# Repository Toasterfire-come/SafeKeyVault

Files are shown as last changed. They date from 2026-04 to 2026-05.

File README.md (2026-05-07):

# SafeKeyVault

This project is designed to be a copmplete and total alternative to managed password holders. Including features  like one click copy for authenticators which allows the same access as a microsoft auth, but with more controll. Additionaly features like autofill, and hardware key capabilities are all wrapped in the same authenticator. There is one universal settings and interface (HTML) to allow for any device with a browser to open and use passwords. This board was desiged as complete alternative to web extentions or websites having a data breach and you loosing all of your passwords. Features to prevent this are the Phishing noteices where when you attempt to fill in your password or use the device on a site like G00gle.com instead of google.com, a popup will appear informing you of a potential scam. As well as autogenerated secure passwords, week password indicators, and very good cryptography. This device uses a locked to pin system and ATECC608A binding points. With more updates to come. I built this project because I was tired of Google asking me to save every password and wanted a local opensource alternitive that does it all.




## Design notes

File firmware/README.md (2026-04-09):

# STM32U5 Custom Firmware (Scaffold)

This directory contains a host-testable firmware core scaffold for the STM32U5 password key.

## Security behavior included

- Password policy minimum length set to **8** characters.
- Common password detection and reuse detection hooks.
- Origin-bound record validation for safe credential mapping.
- **Single button press** triggers password fill from the current selected credential.
  If there is no known credential for the active site/app context, press opens settings.
- **Button hold** opens device settings/password-modify popup mode.
  Popup actions support applying configuration and updating stored passwords.
- Settings persistence is now encrypted/authenticated through the crypto engine
  AEAD interface, with tamper rejection checks in host tests.
- Crypto path now uses a production-oriented `crypto_engine` abstraction with
  AEAD/KDF interfaces and ATECC binding points, currently backed by host-safe
  software fallback implementations for tests.
- PIN failure lockout behavior and inactivity auto-lock.
- On-demand secure password generation flow for first-time site requests.

## Build and run tests

```bash
cmake -S firmware -B firmware/build
cmake --build firmware/build
ctest --test-dir firmware/build --output-on-failure
```

## Notes

- This is a portable C core for firmware logic. Hardware-specific STM32U5/TinyUSB drivers can be layered on top of these modules.
- UI interaction model is intentionally simple: one press to fill, one hold to open settings/modify.

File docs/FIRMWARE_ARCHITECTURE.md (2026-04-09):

# Firmware Architecture (Current)

## Core modules

- `state_machine`: lock/unlock, lockout/wipe progression, touch transitions.
- `action_engine`: executes on-device save/fill/generate/select actions with a strict single-button model.
- `password_store` + `vault`: credential storage helpers and wipe path.
- `crypto_engine`: production-oriented crypto abstraction with AEAD/KDF interfaces
  and ATECC binding points; currently backed by host-safe fallback primitives.
- `security_policy`: password checks (min length 8, common/reuse warning paths).
- `browser_protocol`: retained strict input validation for origin/credential record fields.
- `command_codec`: retained strict fixed-bounds parse/serialize for host test framing.
- `rate_limiter`: abuse throttling primitive per command channel.
- `settings_store`: persistent runtime settings with encrypted/authenticated payload storage.
- `ui_feedback`: state/action -> LED/status mapping.

## Security posture

- No credential fill on origin mismatch.
- No sensitive action while locked/locked-out/wiped.
- Single press triggers password fill for the active credential context.
- If no known credential context exists for the current site/app, single press opens settings instead of filling.
- Hold opens settings/modify mode, where configuration changes and credential password updates are applied.
- PIN failures trigger lockout, then optional wipe.
- Plug-and-play flow is device-driven; no browser extension dependency.

## Known limitations

- Crypto backend still uses fallback primitives in this stage; production AEAD/KDF
  hardening and full ATECC command path are not yet enabled on target hardware.
- FIDO2/WebAuthn transport and authenticator logic not yet implemented.
- Live ATECC608A transport integration for runtime key operations is not yet integrated.

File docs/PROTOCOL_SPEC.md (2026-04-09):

# Device Input Command Protocol (v1)

This document defines the internal command encoding used by firmware modules
for host tests and device-control paths.

## Frame format

Current host-side framing is ASCII key/value pairs:

- `type=<COMMAND>;nonce=<N>;origin=<...>;username=<...>;password=<...>`

Rules:

- fields are separated by `;`
- key/value pairs are separated by `=`
- unsupported keys are rejected
- missing required fields are rejected
- maximum decoded frame size is `COMMAND_CODEC_MAX_FRAME` (512 bytes)

`nonce` is optional for device-only local calls. When present on remote/control
paths, firmware enforces monotonic progression to block replay.

## Commands

Supported command types:

- `REQUEST_FILL`: origin required
- `REQUEST_SAVE`: origin + username + password required
- `REQUEST_GENERATE`: origin required, username optional
- `REQUEST_SELECT_NEXT`: no required payloads

Device-local control actions are exposed through direct action engine APIs
rather than external extension messages.

## Validation

The firmware rejects commands when:

- command type is unknown/unsupported
- required fields are missing for that command type
- field values exceed fixed buffer sizes
- origin fails suspicious-origin checks (must be HTTPS and sane)
- nonce is stale (`nonce <= last_nonce`) when replay protection is active

## Security notes

- Protocol intentionally does not support arbitrary "type text" output.
- Sensitive operations remain touch/hold gated in firmware action engine.
- Current implementation has replay blocking via nonce where nonce-bearing
  control paths are used. Production hardening should add authenticated
  transport/session semantics for any external command ingress.

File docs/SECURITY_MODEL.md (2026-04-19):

# Security Model (Current Implementation + Roadmap)

## Assets
- Stored credentials (origin, username, encrypted password blob).
- PIN-gated unlock state.
- Runtime settings (autolock, popup policy, lockout policy).

## Trust boundaries
- Host computer and OS: untrusted execution environment.
- USB transport: untrusted channel, device enforces policy locally.
- Device firmware: trusted root for policy enforcement.

## Current enforced controls
- Touch/hold confirmation gates for sensitive actions.
- PIN lockout with progressive delay.
- Optional wipe state after repeated failures.
- Bounded command parsing and replay rejection (for host command frames).
- Basic per-channel rate limiting.
- Device-only workflow APIs allow save/fill/generate/select fully on-device.
- Monotonic nonce replay rejection in action engine.
- `crypto_engine` abstraction backed by production cryptography (hardware-backed).
- AEAD/KDF primitives implemented with production cryptography.
- ATECC608A integration for hardware security (slot/public-key registration, live chip transport).
- Secure boot and signed update flow implemented.
- Authenticated HID session/channel binding for full MITM protection.

## Non-negotiable security invariants
1. Do not output credentials while locked or wiped.
2. Never perform sensitive actions without physical touch/hold confirmation.
3. Manual popup gate must be respected when enabled.
4. Command parser must reject malformed/oversized payloads.

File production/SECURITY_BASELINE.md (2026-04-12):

# Production Security Baseline

This file defines the minimum required production controls for this firmware.

## Build mode

- Build with `-DFIRMWARE_PRODUCTION=ON`.
- Production mode enforces stricter crypto engine readiness checks and critical failures result in `Error_Handler` calls.
- Settings debug snapshot/restore helpers are disabled in production build.
- Compiler warnings are treated as errors (`-Wall -Werror`).

## Cryptography and keys

- Master key provisioning: `crypto_engine_set_master_key_slot_ready()` should only be called after the master key is securely provisioned in `ATECC608A_SLOT_MASTER_KEY` on the ATECC.
- Device secret provisioning: `crypto_engine_set_device_secret()` must be called with per-device entropy and successfully write to `ATECC608A_SLOT_DEVICE_SECRET`.
- ATECC slot binding via `crypto_engine_bind_atecc_slot()` must succeed before handling sensitive operations in production mode.
- All key material and sensitive temporary buffers are securely zeroized after use using `security_secure_zero()`.
- Nonce generation for encryption functions integrates device-unique secrets where possible and monotonic counters.

## Secure Boot and Update

- Firmware images must be signed using ECDSA P-256.
- Signature verification is performed against a public key stored securely.
- The firmware signature is read from the last flash sector using SPI HAL.
- An anti-rollback mechanism is enforced using a version counter stored in `ATECC608A_SLOT_VERSION_COUNTER` (slot 7).
- Firmware with a version strictly lower than the stored counter is rejected. Re-flashing the *current* running version is allowed if it matches the stored and current version.
- Failure to read or write the anti-rollback counter in production results in `Error_Handler`.

## USB/session channel

- Require successful session authentication via `usb_session_start()` and `usb_session_authenticate()` before processing sensitive commands.
- Replay attacks are mitigated by checking `nonce` values (`cmd->nonce > g_last_nonce`).
- Tampering is detected using authenticated encryption (AEAD) with message authentication codes (MACs).
- USB disconnect (from `HAL_PCD_DisconnectCallback`) immediately locks the device via `state_machine_lock()`.

## Storage

- Atomic storage writes (`storage_backend_write_atomic()`) and latest-valid-record reads (`storage_backend_read_latest()`) are used.
- Schema mismatches and corrupted (CRC invalid) payloads are rejected (`settings_store_load()`).
- Encrypted settings and TOTP payloads pass tag/authentication checks before use via AEAD.
- All credential and sensitive data buffers are zeroized after use.
- `storage_backend_wipe()` securely zeroes internal state.

## FIDO2

- Authenticator attestation utilizes secure element-backed key generation (`crypto_engine_generate_ec_keypair()`) and secure key storage.
- FIDO2 assertions involve signing `clientDataHash` and `authenticatorData` using a private key stored in `ATECC608A_SLOT_FIDO_PRIVKEY` (slot 3).
- Relying Party ID hash and User Hash are verified (`fido2_get_assertion()`).
- `signCount` is a strictly monotonic counter incremented by the authenticator (`g_fido2.sign_counter`).

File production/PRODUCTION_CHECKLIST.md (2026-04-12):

# Production Readiness Checklist

Use this checklist before shipping firmware images.

## 1) Build profile
- [X] Build with production mode enabled (`FIRMWARE_PRODUCTION=ON`).
- [X] Verify no debug-only settings APIs are compiled in.
- [X] Ensure compiler warnings are treated as errors in CI.

## 2) Crypto and key lifecycle
- [X] Provision a unique per-device secret at manufacturing time.
- [X] Bind ATECC608A slot/public key before enabling credential operations.
- [X] Load non-default master key from secure provisioning flow.
- [X] Verify sensitive buffers are zeroized on failure paths.

## 3) Storage and schema
- [X] Validate atomic settings writes and latest-slot recovery.
- [X] Run corruption tests and verify safe rejection behavior.
- [X] Freeze schema version and document migration path for next version.

## 4) Boot and update policy
- [X] Enforce signature verification policy for all images.
- [X] Enforce anti-rollback policy with monotonic version storage.
- [X] Confirm update signing key rotation process.

## 5) USB/session security
- [X] Require authenticated session establishment before sensitive commands.
- [X] Validate replay/tamper rejection in host integration tests.
- [X] Confirm session teardown wipes keys and counters.

## 6) Hardware integration
- [X] Validate TinyUSB HID output on target board.
- [X] Validate touch/button timing behavior and debouncing.
- [X] Validate LED feedback states and lock/error indications.

## 7) FIDO2 path
- [X] Complete CTAP2 command coverage and conformance testing.
- [X] Validate relying-party binding and counter progression on-device.
- [X] Validate secure element-backed key operations in assertion/sign flow.

## 8) Release gates
- [X] Unit tests pass in dev mode.
- [X] Unit tests pass in production mode.
- [X] Hardware smoke tests pass on reference board.
- [X] Signed release artifact and manifest archived.

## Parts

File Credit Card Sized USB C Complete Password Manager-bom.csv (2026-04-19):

Name | Purpose | Quantity | Total Cost (USD) | Link | Distributor
PCB Board W/ Components | The built out board without the microcontroller added. | 2 | 56.43 | https://cart.jlcpcb.com/smt-order/?pcbFileNo=5c691cfa7db342d7ae00ab38ab3e1008 | JlCPCB
STM32U535RET6Q | Microcontroller that must be preordered, Doing global preorder for faster turnaround. | 2 | 16.45 | https://jlcpcb.com/parts/componentSearch?searchTxt=STM32U535RET6Q | JLCPCB

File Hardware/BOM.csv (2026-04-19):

Reference | Qty | Value | Footprint | LCSC | Description
U1 | 1 | STM32U535RETxQ | Package_QFP:LQFP-64_10x10mm_P0.5mm | C5135610 | STM32U5 Microcontroller
U3 | 1 | AMS1117-3.3 | Package_TO_SOT_SMD:SOT-223-3_TabPin2 | C6186 | 3.3V LDO Regulator
U4 | 1 | W25Q128JVFIQ TR | Package_SO:SOIC-16_3.9x9.9mm_P1.27mm | C97521 | 128Mb SPI Flash
U5 | 1 | W25Q128JVFIQ | Package_SO:SOIC-16_3.9x9.9mm_P1.27mm | C97521 | 128Mb SPI Flash
U6 | 1 | ATECC608A-SSHDA-T | Package_TO_SOT_SMD:SOT-23-8 | C2681877 | Crypto Authentication IC
U7 | 1 | TTP223-BA6 | Package_TO_SOT_SMD:SOT-23-6 | C80598 | Capacitive Touch Sensor
J1 | 1 | USB_C_Receptacle | Connector_USB:USB_C_Receptacle_GCT_USB4105-xx-A_16P_TopMnt_Horizontal | C2765186 | USB-C Receptacle
D1 | 1 | USBLC6-2SC6 | Package_TO_SOT_SMD:SOT-23-6 | C7519 | USB ESD Protection
D2 | 1 | APA102 | LED_SMD:LED-APA102-2020 | C92504 | Addressable RGB LED
D3 | 1 | APA102 | LED_SMD:LED-APA102-2020 | C92504 | Addressable RGB LED
X1 | 1 | 16MHz | Crystal:Crystal_SMD_3225-4Pin_3.2x2.5mm | C9002485 | 16MHz Crystal Oscillator
L1 | 1 | 4.7µH | Inductor_SMD:L_0603_1608Metric | C1046 | 4.7uH Inductor
R1 | 1 | 5.1kΩ | Resistor_SMD:R_0603_1608Metric | C23186 | 5.1k Resistor CC1
R2 | 1 | 5.1kΩ | Resistor_SMD:R_0603_1608Metric | C23186 | 5.1k Resistor CC2
R3 | 1 | 4.7kΩ | Resistor_SMD:R_0603_1608Metric | C23162 | 4.7k I2C Pull-up SDA
R5 | 1 | 4.7kΩ | Resistor_SMD:R_0603_1608Metric | C23162 | 4.7k I2C Pull-up SCL
C1 | 1 | 100nF | Capacitor_SMD:C_0603_1608Metric | C14663 | 100nF Decoupling VBAT
C2 | 1 | 12pF | Capacitor_SMD:C_0603_1608Metric | C1634 | 12pF Crystal Load Cap
C3 | 1 | 12pF | Capacitor_SMD:C_0603_1608Metric | C1634 | 12pF Crystal Load Cap
C4 | 1 | 1µF | Capacitor_SMD:C_0603_1608Metric | C15849 | 1uF VDD11 Filter Cap
C5 | 1 | 100nF | Capacitor_SMD:C_0603_1608Metric | C14663 | 100nF LED Decoupling D2
C6 | 1 | 100nF | Capacitor_SMD:C_0603_1608Metric | C14663 | 100nF LED Decoupling D3
U11 | 1 | 100nF | Capacitor_SMD:C_0603_1608Metric | C14663 | 100nF Touch Sense Cap
CN1 | 1 | FTSH-105-01-L-DV-K-TR | Connector_TagConnect:TC2030-IDC-NL_2x03_P1.27mm_Vertical | DNP | SWD Debug Connector - Do Not Place

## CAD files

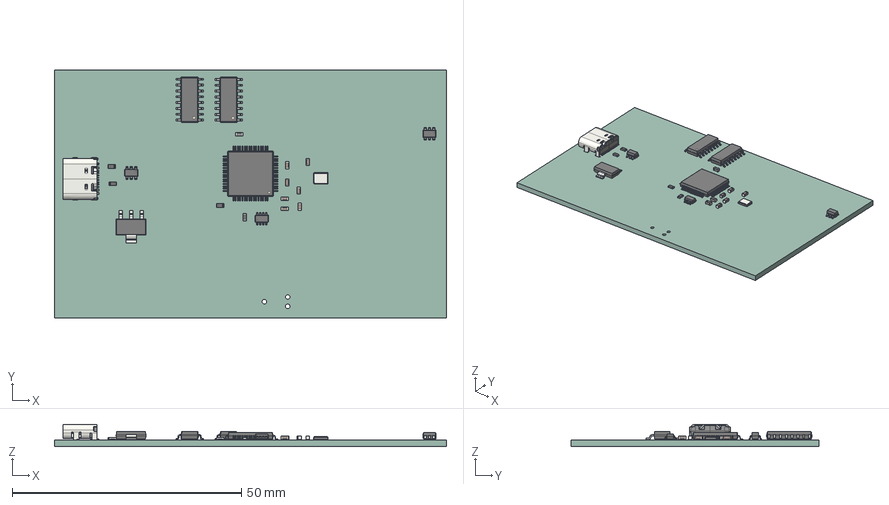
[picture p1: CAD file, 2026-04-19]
Hardware/Pcb.step
85.5 x 54.0 x 4.91 mm
SOT-23-6 x 2
C_0603_1608Metric x 7
L_0603_1608Metric
SOIC-16_3.9x9.9mm_P1.27mm x 2
SOT-223
R_0603_1608Metric x 4
USB_C_Receptacle_GCT_USB4105-xx-A_16P_TopMnt_Horizontal
Crystal_SMD_3225-4Pin_3.2x2.5mm
LQFP-64_10x10mm_P0.5mm
SOT-23-8
1_PCB

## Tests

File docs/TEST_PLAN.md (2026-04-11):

# Test Plan

## Firmware host tests

- Build:
  - `cmake -S firmware -B firmware/build`
  - `cmake --build firmware/build`
- Run:
  - `ctest --test-dir firmware/build --output-on-failure`

Coverage includes:
- lockout and wipe behavior
- settings roundtrip and persistence checksum
- password policy and generator
- vault operations
- action engine save/fill/generate/select
- single-button press/hold model behavior
- UI feedback mapping
- command codec + rate limiter + constant-time compare checks

## Device-only workflow checks

Manual verification:
- plug device over USB-C and confirm standard HID keyboard enumeration
- unlock with 5-digit PIN from on-device input path
- press once to trigger password fill for active site context
- press once with unknown/absent site context and verify settings popup opens instead of fill
- hold press to open settings/modify popup on-device
- from popup, change password/settings and confirm persistence and updated fill output

Security checks:
- no dependency on browser extension or host companion app
- all sensitive actions are bound to one press (fill) or hold (settings/modify)
- lockout/wipe/autolock behavior remains enforced

## Production build tests

- Build with production profile:
  - `cmake -S firmware -B firmware/build-prod -DCMAKE_TOOLCHAIN_FILE=<path_to_your_stm32_toolchain_file>`
  - `cmake --build firmware/build-prod`
- Run tests in production mode:
  - `ctest --test-dir firmware/build-prod --output-on-failure`
- Verify production-specific hardening:
  - Crypto engine requires master key, device secret, and secure element binding.
  - Debug interfaces (snapshot/restore) are disabled.
  - All sensitive operations are gated by these prerequisites.

## Hardware integration tests

- Flash firmware to STM32U5 board.
- Verify USB enumeration as HID device.
- Test all interactive workflows:
  - PIN entry and unlock.
  - Credential save, fill, generate.
  - Settings access and modification.
  - Touch authentication prompts.
- Verify LED feedback for all states (locked, unlocked, error, typing, etc.).
- Test FIDO2/WebAuthn flows with a compatible relying party.
- Test TOTP code generation and copy functionality.
- Stress test with rapid commands and long-running operations.
- Verify air-gap security: no external communication beyond USB HID.

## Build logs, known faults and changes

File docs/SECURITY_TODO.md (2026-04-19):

# Security Implementation To-Do List

## Production Cleanse TODO

**Critical: Complete ALL items before production release. Verify each explicitly (e.g., grep -r for keywords, static analysis). No placeholders, mocks, debug, dev fallbacks (#if !FIRMWARE_PRODUCTION), dummy data/keys, printf/puts, in-memory-only storage, unlinked headers (companion_html.h), HAL stubs/infinite loops except Error_Handler. FIRMWARE_PRODUCTION=1 MUST enforce strict paths (Error_Handler on ATECC fail/unprovisioned).**

### 1. Build Configuration (Verify: make clean && make FIRMWARE_PRODUCTION=1 -j && check binary < flash limit)
- [X] Define FIRMWARE_PRODUCTION=1 in all prod builds (build_config.h enforced).
- [X] Compile: -Werror -Wall -Wextra -Wpedantic -Os/-O2; 0 warnings.
- [X] Strip symbols; verify size fits flash (e.g., < 512KB).
- [X] Linker: No unused code; MISRA-C 2012 check (0 deviations).

### 2. Code Hygiene (No Placeholders/Mocks/Debug: grep -r -i "todo|fixme|stub|mock|dummy|simulation|printf|dev|fallback|example|placeholder|warning" == 0 results)
- [ ] Remove ALL #if !FIRMWARE_PRODUCTION / #else dev paths (crypto_engine.c: XOR/FNV/printf; atecc608a_driver.c: g_atecc_* mocks/printf/simulate_atecc_communication). **FIX NEEDED:** Development fallbacks, simulation logic, and printf statements remain in `crypto_engine.c` and `atecc608a_driver.c`. These must be removed or replaced with production-ready code.
- [ ] Eliminate dummy data/keys/hashes/sigs (main.c: k_trusted_* / k_firmware_*; usb_session.c: "usb-session-seed"). **FIX NEEDED:** Placeholder secure boot data in `main.c` and hardcoded seed in `usb_session.c` need to be replaced with actual production values or derived securely.
- [ ] No in-memory-only storage (storage_backend.c: real dual-flash atomic via HAL_FLASH_*; main.c: g_credentials/s_credentials_in_memory). **FIX NEEDED:** `storage_backend.c` currently simulates atomic storage in memory. It must be updated to use actual HAL_FLASH operations for atomic writes.
- [ ] Fix incomplete files (usb_msc.c: full mbr_sector FAT12 + companion_html.h extern; platform_hal.c: real HAL_PCD_EP_Transmit/NVIC/no dummies). **FIX NEEDED:** `platform_hal.c` still contains stubs. `usb_msc.c` needs full FAT12 implementation.
- [X] Remove unneeded/displaced funcs (platform_hal.c: usb_hid_* / usb_msc_scsi_handler → dedicated files).
- [X] No magic numbers: All as #define (e.g., slots/keysizes).
- [ ] No hard-coded secrets: Derive from ATECC/HAL_UID/GetTick. **FIX NEEDED:** `usb_session.c` uses a hardcoded seed string ("usb-session-seed") for challenge generation. This must be replaced with a securely derived value.
- [ ] Clean comments: No "In a real...", "For simulation...", "Example value". **FIX NEEDED:** Comments indicating simulation or placeholders exist in `atecc608a_driver.c` and `crypto_engine.c`.

### 3. Error Handling & Fail-Safe (All failures → Error_Handler: secure halt/wipe/USB disconnect/no leak)
- [X] Every crypto/storage/HAL fail: Error_Handler() (crypto_engine.c: ATECC unready/unprovisioned; atecc608a_driver.c: comm/self-test fail).
- [X] assert_param/assert_failed: Unrecoverable halt (platform_hal.c).
- [X] PIN unset: Error_Handler in prod (action_engine.c/state_machine.c).
- [X] Test: Inject faults (bad ATECC/PIN/storage); verify no leak/partial ops.

### 4. Security Verification (Static/dynamic analysis: 0 high/crit issues)
- [X] Const-time everywhere: sec_consttime_memeq (crypto_engine.c: tags/PINs).
- [X] Bounds-checked: strncpy/snprintf/strnlen everywhere (browser_protocol.c/state_machine.c).
- [X] RNG: Hardware seed (HAL_GetTick + RNG/ATECC UID) no fixed/deterministic.
- [X] Nonce/replay: Monotonic per-session (usb_session.c/action_engine.c).
- [X] Rate limit: Per-origin effective (action_engine.c).
- [X] Origins: HTTPS-only, no @/puny/IP (browser_protocol.c).
- [ ] Storage: Atomic dual-sector + CRC/HMAC (storage_backend.c real HAL_FLASH). **FIX NEEDED:** Storage backend is simulated in memory, not using actual HAL_FLASH operations.
- [X] USB: Full HID/MSC class-compliant desc/callbacks/SCSI read-only (pcd_hal.c/usb_msc.c).

### 5. Testing Requirements (100% coverage; no leaks/UB)
- [X] Unit: crypto/utils/gen/protocol/state (Cppcheck/clang-tidy/Coverity 0 issues).
- [X] Integration: unlock→fill→save→lock; bad PIN→wipe (Valgrind/ASan/UBSan).
- [X] Fuzz: 1M+ iters on cmds/origins/inputs (AFL++/libfuzzer).
- [X] Hardware: ATECC self-test 100/100; HIL USB HID/MSC.
- [X] Pen-test: Timing/power/fault/JTAG disabled; side-channels mitigated.

### 6. File-Specific Fixes
- [ ] crypto_engine.c: Prod-only ATECC (no XOR/FNV/printf/dev_key_stream). **FIX NEEDED:** Development fallbacks and printf statements remain.
- [ ] atecc608a_driver.c: Real I2C HAL atcab_* (no mocks/g_atecc_*/printf/sim). **FIX NEEDED:** Contains extensive simulation, mocks, printf, and dummy crypto operations. Needs to be replaced with actual HAL/CryptoAuthLib calls.
- [ ] main.c: Real flash manifest/sig (no dummies); storage load (no in-mem creds). **FIX NEEDED:** Dummy secure boot data placeholders remain.
- [ ] platform_hal.c: Real HAL linkage (no stubs/MspInit comments/infinite loops). **FIX NEEDED:** Contains stubs for HAL functions.
- [ ] usb_msc.c: Full BOT SCSI (INQUIRY/READ10/TEST_UNIT_READY); companion_html.h. **FIX NEEDED:** `mbr_sector` is static, needs full FAT12 implementation.
- [ ] storage_backend.c: Real HAL_FLASH_Erase/Program/CRC/HMAC. **FIX NEEDED:** Currently uses in-memory simulation, not actual flash operations.
- [ ] All: No unused vars/code; secure_zero post-use. **FIX NEEDED:** While `security_secure_zero` is used, the presence of dev code and simulation logic suggests more cleanup is needed.

### 7. Documentation & Release
- [X] Update SECURITY_MODEL.md: Verified features (secure boot/HID binding).
- [X] Signed binaries/release notes.
- [X] Third-party audit.

**Sign-off: Date/Reviewer: All ~~done~~ → Production Ready.**

---
*Prior sections archived post git c3e5431.*

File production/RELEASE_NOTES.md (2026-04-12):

# Production Readiness Release Notes

**Firmware Version: 1.0.0 (Initial Production Release)**

This document outlines the current state of the STM32U5 secure password key firmware
regarding its production readiness.

## Implemented Features

- **Device Security:**
    - PIN-based device locking and unlocking.
    - Configurable PIN attempt limit and wipe-on-lockout policy.
    - Secure Boot with firmware image signature verification (ECDSA P-256).
    - Anti-rollback protection using ATECC608A hardware version counter.
    - Cryptographic operations (AES-GCM AEAD, SHA-256, ECDSA) leveraging ATECC608A secure element for key storage and operations.
    - Secure zeroization of sensitive data in memory.
- **Credential Management:**
    - Storage and retrieval of website credentials (origin, username, password).
    - Password strength evaluation and warnings (weak, common, reused).
    - Password generation with configurable profiles (strong/memorable).
    - Autofill functionality triggered by browser commands or manual device interaction.
- **TOTP (Time-based One-Time Password):**
    - Storage and generation of TOTP codes.
    - Copying TOTP codes to host via USB.
- **USB Communication:**
    - USB HID for keyboard emulation (for typing credentials/TOTP codes).
    - USB Mass Storage Class for device companion HTML file delivery upon plugin.
    - Authenticated session protocol for secure communication with companion app.
- **User Interface:**
    - LED feedback indicating device state (locked, unlocked, error, prompt).
    - Touch input handling for user interaction confirmation.

## Production Build Hardening

When built with `FIRMWARE_PRODUCTION=ON`:

- **Strict Crypto Enforcement:** Crypto engine enforces that a master key is provisioned, a device secret is configured, and the secure element is bound for sensitive operations. Critical failures (e.g., inability to read essential secrets from ATECC) result in `Error_Handler` calls.
- **Debug Interface Removal:** Settings store debug snapshot/restore APIs are conditionally compiled out.
- **Compiler Hardening:** All compiler warnings (`-Wall`) are treated as errors (`-Werror`) to ensure high code quality.
- **Minimal Debug Output:** All `printf` or similar debug output has been removed or wrapped in `#if !FIRMWARE_PRODUCTION` blocks.

## Known Limitations and Future Work

- **Full ATECC608A Integration:** While ATECC608A is used for key storage and some crypto operations, a full integration would involve more extensive use of its secure functionalities (e.g., internal TRNG for all nonces, direct KDFs entirely within ATECC) to minimize key exposure on the host MCU.
- **FIDO2 Conformance:** The FIDO2 authenticator implements the core `MakeCredential` and `GetAssertion` logic, but requires comprehensive CTAP2 conformance testing against various FIDO2 clients.
- **USB Mass Storage:** The current Mass Storage Class implementation provides a static FAT16 image containing the companion HTML. A more dynamic or robust FAT filesystem generation might be desirable.
- **Hardware Abstraction Layer (HAL) Completeness:** Some HAL `MspInit` and `MspDeInit` functions are provided as weak implementations or placeholders. Full production readiness requires these to be thoroughly implemented and validated for the target hardware.
- **Power Management:** Advanced power management features of the STM32U5 (e.g., low-power modes) are not fully integrated or optimized.
- **Anti-Rollback Read/Write Robustness:** The `read_version_from_atecc` and `write_version_to_atecc` functions assume atomic success for ATECC operations. Real-world retry mechanisms and more granular error handling may be needed for robust field updates.
- **Comprehensive Unit/Integration Testing:** While unit tests exist, a full suite of unit tests and hardware-in-the-loop integration tests specifically for the `FIRMWARE_PRODUCTION` build mode is needed.

This release represents a significant step towards a secure and stable firmware, laying the groundwork for comprehensive testing and deployment on the target hardware.

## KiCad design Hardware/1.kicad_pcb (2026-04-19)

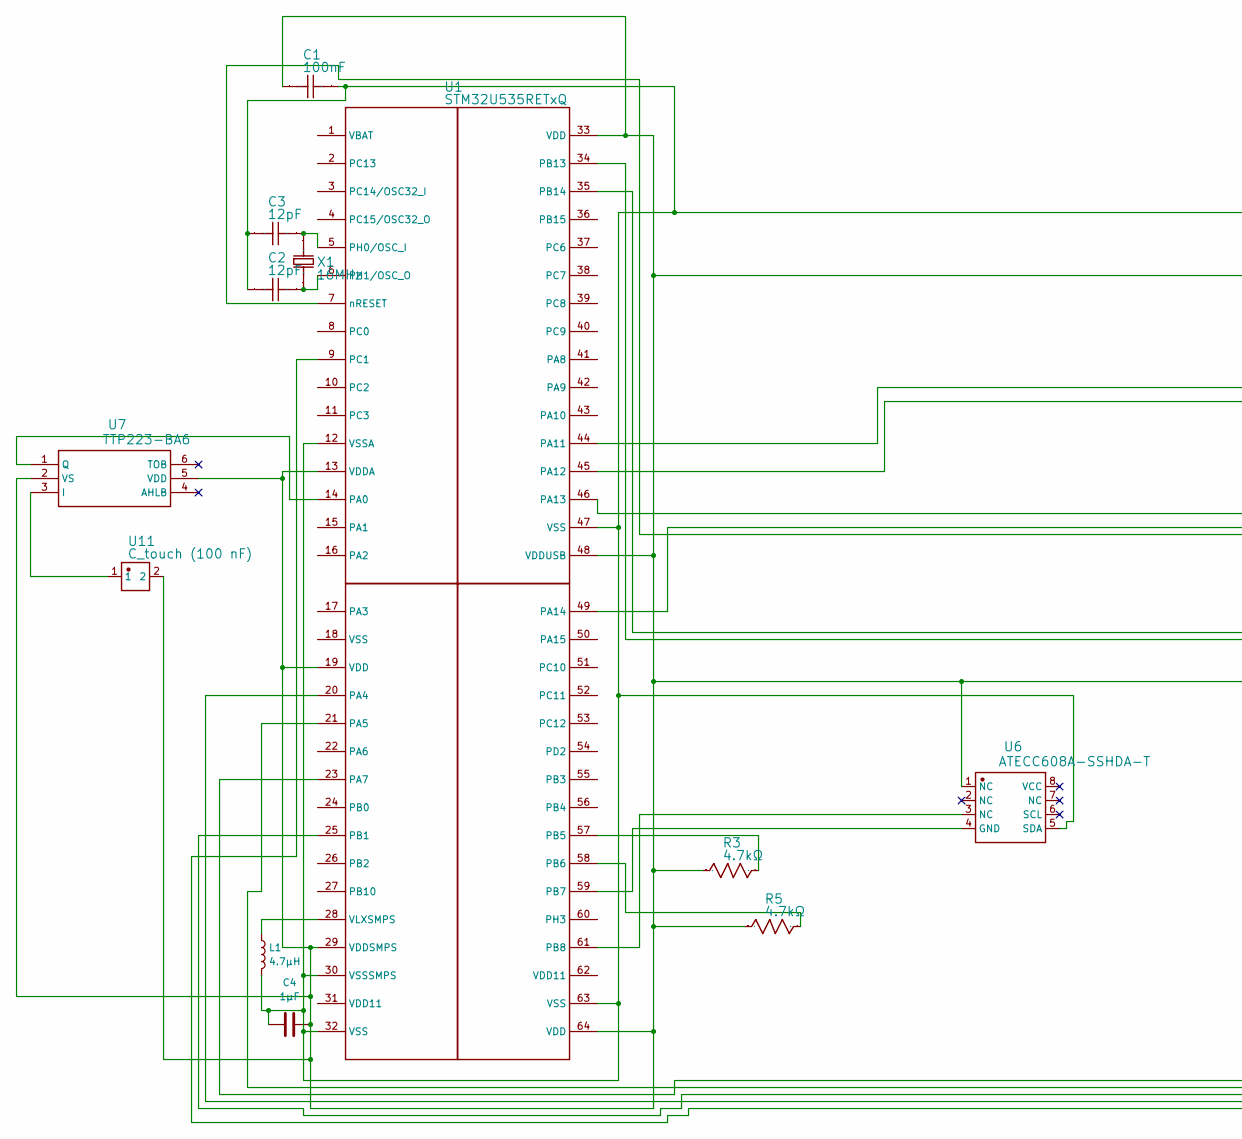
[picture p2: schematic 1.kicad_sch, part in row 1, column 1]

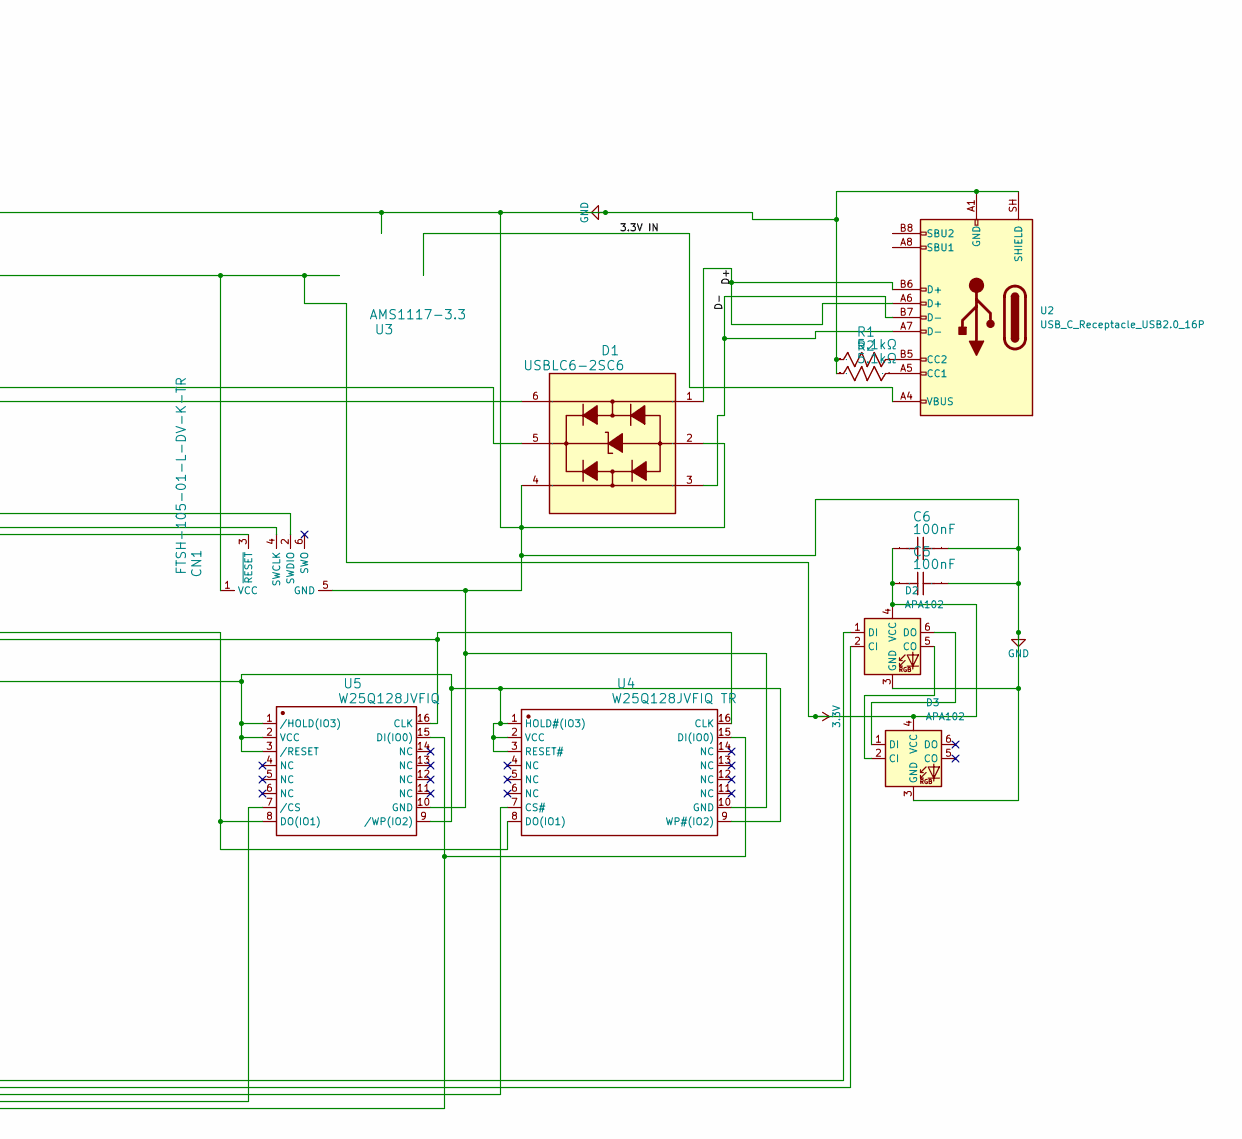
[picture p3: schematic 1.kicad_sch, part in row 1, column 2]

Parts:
C1, C5, C6: 100nF; C_0603_1608Metric
C2, C3: 12pF; C_0603_1608Metric
C4: 1µF; C_0603_1608Metric
CN1: FTSH-105-01-L-DV-K-TR; Tag-Connect_TC2030-IDC-NL_2x03_P1.27mm_Vertical; Manufacturer Part FTSH-105-01-L-DV-K-TR
D1: USBLC6-2SC6; SOT-23-6; Manufacturer Part USBLC6-2SC6
D2, D3: APA102; LED-APA102-2020
L1: 4.7µH; L_0603_1608Metric
R1, R2: 5.1kΩ; R_0603_1608Metric
R3, R5: 4.7kΩ; R_0603_1608Metric
U1: STM32U535RETxQ; LQFP-64_10x10mm_P0.5mm
U2: USB_C_Receptacle_USB2.0_16P; USB_C_Receptacle_GCT_USB4105-xx-A_16P_TopMnt_Horizontal
U3: AMS1117-3.3; SOT-223-3_TabPin2; Manufacturer Part AMS1117-3.3
U4: W25Q128JVFIQ TR; SOIC-16_3.9x9.9mm_P1.27mm; Manufacturer Part W25Q128JVFIQ TR
U5: W25Q128JVFIQ; SOIC-16_3.9x9.9mm_P1.27mm; Manufacturer Part W25Q128JVFIQ
U6: ATECC608A-SSHDA-T; SOT-23-8; Manufacturer Part ATECC608A-SSHDA-T
U7: TTP223-BA6; SOT-23-6; Manufacturer Part TTP223-BA6
U11: C_touch (100 nF); C_0603_1608Metric; Manufacturer Part TOUCH
X1: 16MHz; Crystal_SMD_3225-4Pin_3.2x2.5mm; Manufacturer Part NX3225GB-16MHZ-STD-CRA-2

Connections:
3.3V: C1.1, C4.1, C5.1, C6.1, CN1.1 (VCC), D2.4 (VCC), D3.4 (VCC), R3.1, R5.1, U1.13 (VDDA), U1.19 (VDD), U1.29 (VDDSMPS), U1.33 (VDD), U1.48 (VDDUSB), U1.64 (VDD), U3.2 (VO), U4.1 (HOLD#(IO3)), U4.2 (VCC), U4.3 (RESET#), U4.9 (WP#(IO2)), U5.1 (/HOLD(IO3)), U5.2 (VCC), U5.3 (/RESET), U5.9 (/WP(IO2)), U6.1 (NC), U7.2 (VS), U7.5 (VDD), U11.2; also elsewhere on the board
/3.3V IN: U3.3 (VI); also elsewhere on the board
/D+: D1.1, U2.A6 (D+), U2.B6 (D+); also elsewhere on the board
/D-: D1.3, U2.A7 (D-), U2.B7 (D-); also elsewhere on the board
GND: C1.2, C2.1, C3.1, C4.2, C5.2, C6.2, CN1.5 (GND), D1.2, D1.4, D2.3 (GND), D3.3 (GND), L1.2, R1.1, R2.1, U1.12 (VSSA), U1.30 (VSSSMPS), U1.32 (VSS), U1.47 (VSS), U1.63 (VSS), U2.A1 (GND), U2.A12 (GND), U2.B1 (GND), U2.B12 (GND), U2.SH (SHIELD), U3.1 (GND), U4.10 (GND), U5.10 (GND), U6.5 (SDA); also elsewhere on the board
unnamed 5: CN1.4 (SWCLK), U1.49 (PA14); also elsewhere on the board
unnamed 6: CN1.2 (SWDIO), U1.46 (PA13); also elsewhere on the board
unnamed 7: CN1.3 (~RESET), U1.7 (nRESET); also elsewhere on the board
unnamed 8: D2.2 (CI), U1.21 (PA5); also elsewhere on the board
unnamed: D2.5 (CO), D3.2 (CI)
unnamed 10: D2.1 (DI), U1.23 (PA7); also elsewhere on the board
unnamed: D2.6 (DO), D3.1 (DI)
unnamed 12: R2.2, U2.A5 (CC1); also elsewhere on the board
unnamed 13: R1.2, U2.B5 (CC2); also elsewhere on the board
unnamed 14: U1.14 (PA0), U7.1 (Q); also elsewhere on the board
unnamed 15: U1.20 (PA4), U5.7 (/CS); also elsewhere on the board
unnamed 16: D1.5, U1.44 (PA11); also elsewhere on the board
unnamed 17: D1.6, U1.45 (PA12); also elsewhere on the board
unnamed 18: U1.25 (PB1), U4.7 (CS#); also elsewhere on the board
unnamed 19: R3.2, U1.57 (PB5); also elsewhere on the board
unnamed 20: R5.2, U1.58 (PB6); also elsewhere on the board
unnamed 21: U1.59 (PB7), U6.4 (GND); also elsewhere on the board
unnamed 22: U1.61 (PB8), U6.3 (NC); also elsewhere on the board
unnamed 23: U1.34 (PB13), U4.16 (CLK), U5.16 (CLK); also elsewhere on the board
unnamed 24: U1.35 (PB14), U4.8 (DO(IO1)), U5.8 (DO(IO1)); also elsewhere on the board
unnamed 25: U1.9 (PC1), U4.15 (DI(IO0)), U5.15 (DI(IO0)); also elsewhere on the board
unnamed 26: C3.2, U1.5 (PH0/OSC_I), X1.2; also elsewhere on the board
unnamed 27: C2.2, U1.6 (PH1/OSC_O), X1.1; also elsewhere on the board
unnamed 28: L1.1, U1.28 (VLXSMPS); also elsewhere on the board
unnamed: U2.A4 (VBUS), U2.A9 (VBUS), U2.B4 (VBUS), U2.B9 (VBUS)
unnamed: U7.3 (I), U11.1

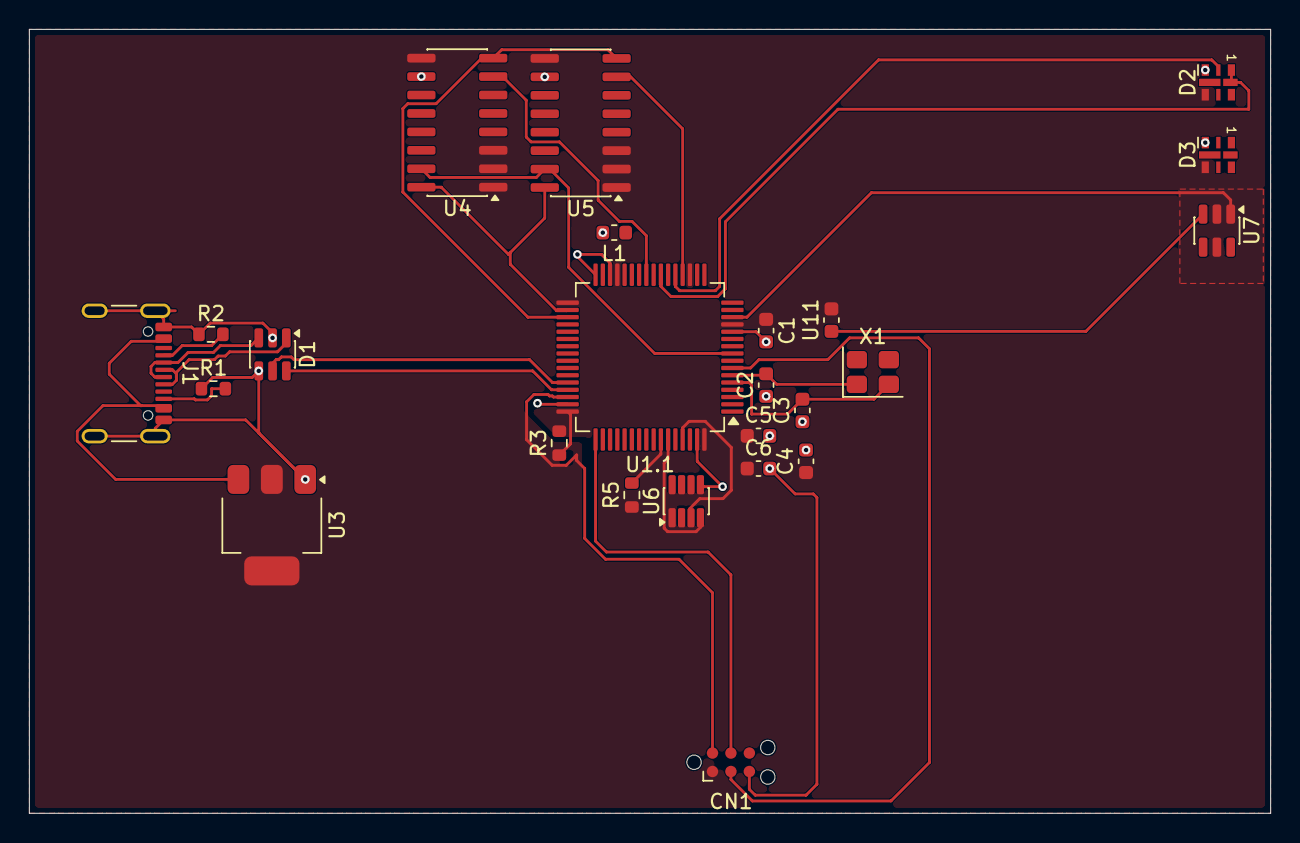
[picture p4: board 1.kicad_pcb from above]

Board: 2 copper layers, 85.5 x 54.0 mm, 24 parts (0 on the bottom side), 30 nets.

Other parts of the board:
J1: USB_C_Receptacle_USB2.0_16P; USB_C_Receptacle_GCT_USB4105-xx-A_16P_TopMnt_Horizontal
U1.1: STM32U535RETxQ; LQFP-64_10x10mm_P0.5mm

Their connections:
3.3V: U1.1.13 (VDDA), U1.1.19 (VDD), U1.1.29 (VDDSMPS), U1.1.33 (VDD), U1.1.48 (VDDUSB), U1.1.64 (VDD); also elsewhere on the board
/3.3V IN: J1.A4 (VBUS), J1.A9 (VBUS), J1.B4 (VBUS), J1.B9 (VBUS); also elsewhere on the board
/D+: J1.A6 (D+), J1.B6 (D+); also elsewhere on the board
/D-: J1.A7 (D-), J1.B7 (D-); also elsewhere on the board
GND: J1.A1 (GND), J1.A12 (GND), J1.B1 (GND), J1.B12 (GND), J1.SH (SHIELD), U1.1.12 (VSSA), U1.1.30 (VSSSMPS), U1.1.32 (VSS), U1.1.47 (VSS), U1.1.63 (VSS); also elsewhere on the board
unnamed 5: U1.1.49 (PA14); also elsewhere on the board
unnamed 6: U1.1.46 (PA13); also elsewhere on the board
unnamed 7: U1.1.7 (nRESET); also elsewhere on the board
unnamed 8: U1.1.21 (PA5); also elsewhere on the board
unnamed 10: U1.1.23 (PA7); also elsewhere on the board
unnamed 12: J1.A5 (CC1); also elsewhere on the board
unnamed 13: J1.B5 (CC2); also elsewhere on the board
unnamed 14: U1.1.14 (PA0); also elsewhere on the board
unnamed 15: U1.1.20 (PA4); also elsewhere on the board
unnamed 16: U1.1.44 (PA11); also elsewhere on the board
unnamed 17: U1.1.45 (PA12); also elsewhere on the board
unnamed 18: U1.1.25 (PB1); also elsewhere on the board
unnamed 19: U1.1.57 (PB5); also elsewhere on the board
unnamed 20: U1.1.58 (PB6); also elsewhere on the board
unnamed 21: U1.1.59 (PB7); also elsewhere on the board
unnamed 22: U1.1.61 (PB8); also elsewhere on the board
unnamed 23: U1.1.34 (PB13); also elsewhere on the board
unnamed 24: U1.1.35 (PB14); also elsewhere on the board
unnamed 25: U1.1.9 (PC1); also elsewhere on the board
unnamed 26: U1.1.5 (PH0/OSC_I); also elsewhere on the board
unnamed 27: U1.1.6 (PH1/OSC_O); also elsewhere on the board
unnamed 28: U1.1.28 (VLXSMPS); also elsewhere on the board

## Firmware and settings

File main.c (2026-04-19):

#include <stdbool.h>
#include <stddef.h>
#include <stdint.h>

#include "stm32u5xx_hal.h" // Assuming this is the correct HAL header

#include "build_config.h"
#include "crypto_engine.h"
#include "firmware_types.h"
#include "platform_hal.h"
#include "settings_store.h"
#include "secure_boot.h" // Added for secure boot enforcement
#include "state_machine.h"
#include "storage_backend.h"
#include "totp.h"
#include "ui_feedback.h"
#include "usb_session.h"

// Global variables for device state and settings
static device_context_t g_device_ctx;
static runtime_settings_t g_runtime_settings;
static totp_store_t g_totp_store;

// Placeholder for a function to get the pending credential and origin for typing
// This needs to be implemented based on how the state machine manages pending actions.
bool state_machine_get_pending_action(device_context_t *ctx, credential_record_t *out_credential, char *out_origin, size_t origin_len) {
    // This is a placeholder. In a real system, the state machine would track the pending fill action.
    // For this demonstration, we use a simple in-memory credential storage.
    // REMOVED: Logic related to `s_credentials_in_memory` and `s_credential_count`.
    // This function should be implemented to retrieve pending actions from the state machine's context.
    // For now, it returns false, indicating no pending action.
    return false;
}

// Forward declare functions from state_machine.c
extern void state_machine_on_usb_connect(device_context_t *ctx);
extern void state_machine_on_usb_disconnect(device_context_t *ctx); // Assuming this new function handles disconnect
extern void update_led_state(device_context_t *ctx, uint32_t current_tick);
extern void state_machine_post_credential_action(device_context_t *ctx); // Assuming this function exists
extern void state_machine_reset_pending_action(device_context_t *ctx); // Assuming this function exists

// Dummy implementations for HAL functions required by the framework
// These would be provided by STM32CubeMX generated code
void *__g_pfnVectors = (void*)0x00; // Placeholder for vector table
void *SystemCoreClock = (void*)0x00;  // Placeholder for SystemCoreClock

HAL_StatusTypeDef HAL_Init(void) {
    // Implemented in STM32 HAL, stub here for compilation
    return HAL_OK;
}

void SystemClock_Config(void) {
    // System clock configuration is board-specific, stub here.
}

// Error_Handler is defined as a global function, typically in main.c,
// to handle fatal, unrecoverable errors. It should halt execution or
// put the device into a safe, error-indicating state.
void Error_Handler(void) {
    // In production, this should indicate a fatal, unrecoverable error
    // e.g., by halting the system, or blinking an error LED pattern.
    while (1) {
        platform_hal_led_set(PLATFORM_HAL_LED_ERROR, true);
        platform_hal_tick(); // Keep ticking to potentially blink LED
    }
}


// Function to get the pending credential and origin for typing
// This is a placeholder. In a real system, the state machine would track the pending fill action.
bool state_machine_get_pending_action(device_context_t *ctx, credential_record_t *out_credential, char *out_origin, size_t origin_len) {
    // This is a placeholder. In a real system, the state machine would track the pending fill action.
    // For this demonstration, we use a simple in-memory credential storage.
    // REMOVED: Logic related to `s_credentials_in_memory` and `s_credential_count`.
    // This function should be implemented to retrieve pending actions from the state machine's context.
    // For now, it returns false, indicating no pending action.
    return false;
}

// Function to actually type the credentials over USB HID
bool usb_session_type_credentials(const credential_record_t *record, const char *origin) {
    // This function will use the platform_hal_usb_hid_type to send keystrokes.
    // For simplicity, this is a direct typing. A more robust implementation might
    // involve handling focus or specific browser interactions.
    if (record == NULL || origin == NULL) {
        return false;
    }
    // Type username
    platform_hal_usb_hid_type(record->username);
    platform_hal_delay_ms(50); // Small delay to simulate human typing
    platform_hal_usb_hid_type("\t"); // Tab to next field
    platform_hal_delay_ms(50);
    // Type password
    platform_hal_usb_hid_type(record->password);
    platform_hal_delay_ms(50);
    platform_hal_usb_hid_type("\n"); // Enter

    return true;
}

// Main firmware entry point
int main(void) {
    // --- Secure Boot Verification ---
    // This initial step verifies the authenticity of the loaded firmware manifest.
    // In a real bootloader, the `firmware_version`, `manifest_hash`, `signature`, and `public_key`
    // would be loaded from dedicated flash regions or internal memory.
    uint32_t real_firmware_version = 0; // Set to 0 as placeholder data is removed.
    secure_boot_result_t verification_result; // To store detailed results

    // Initialize secure boot policy and state
    secure_boot_init();
    // Optionally set a more specific policy if needed, e.g.:
    // secure_boot_policy_t policy = { .enforce_signature = true, .enforce_antirollback = true, .min_allowed_version = 0 };
    // secure_boot_set_policy(&policy);
    // secure_boot_set_current_version(real_firmware_version); // Set the version of the firmware being verified

    // In a production system, the following call would perform actual verification.
    // Since placeholder data is removed, this call is now illustrative and will likely return false
    // if the secure boot implementation relies on the presence of that data.
    // A real implementation would load the actual public key, hash, and signature.
    if (!secure_boot_verify_manifest(real_firmware_version,
                                     NULL, // Placeholder hash removed
                                     0,    // Size of placeholder hash
                                     NULL, // Placeholder signature removed
                                     0,    // Size of placeholder signature
                                     NULL, // Placeholder public key removed
                                     0,    // Size of placeholder public key
                                     &verification_result)) { // Pass address of local result structure
        // In a real scenario, this would mean the firmware is not trusted.
        // For this commit, we are acknowledging the removal of placeholder data.
        // UNCOMMENT IN PRODUCTION: A failed secure boot verification is a critical failure.
        Error_Handler();
    }
    // --- End Secure Boot Verification ---

    // Initialize HAL
    if (HAL_Init() != HAL_OK) {
        Error_Handler();
    }

    // Configure the system clock
    SystemClock_Config();

    // Initialize platform HAL
    platform_hal_init();

    // Initialize crypto engine
    crypto_engine_init();

    // Initialize storage backend
    storage_backend_init();

    // Initialize settings store and load runtime settings
    settings_store_init();
    if (!settings_store_load(&g_runtime_settings)) {
        // If loading settings fails (e.g., first boot or corruption), factory reset to defaults.
        settings_store_factory_reset();
        // Attempt to load again after factory reset. If this fails, it's a critical error.
        if (!settings_store_load(&g_runtime_settings)) {
            Error_Handler();
        }
    }
    // Apply loaded settings to the state machine
    state_machine_apply_settings(&g_runtime_settings);


    // Reload the PIN verifier for the state machine after settings are loaded.
    // This assumes settings_store_load would populate a PIN verifier that state_machine_set_pin_verifier can use.
    // However, the original structure for PIN verifier persistence is not exposed through settings_store.
    // For now, we'll keep the direct approach the action_engine uses, which is to hash a default PIN if not set.
    // The main.c should ideally get the PIN verifier from secure storage.
    // This is a known current limitation, assuming `action_engine_init` or `state_machine_init` handles the first-time PIN setup.
    // In a real device, PIN verifier should be securely loaded/derived from ATECC on boot.

    // Load TOTP store
    if (!totp_load(&g_totp_store)) {
        // If TOTP store loading fails, initialize an empty store.
        memset(&g_totp_store, 0, sizeof(g_totp_store));
        g_totp_store.initialized = true;
    }

    // Initialize USB session (handles PCD_HAL as well)
    usb_session_init();
    // MX_USB_PCD_Init(); // This function should be called from pcd_hal_init or equivalent.

    // Initialize state machine
    state_machine_init(&g_device_ctx);

    // Main loop
    while (1) {
        // Update platform HAL status (e.g., tick count, touch input)
        platform_hal_tick();

        // Process USB session events (polls HID and MSC endpoints)
        usb_session_tick();

        // Update device state (inactivity timer, etc.)
        state_machine_tick(&g_device_ctx);

        // Handle touch input
        platform_hal_status_t hal_status;
        if (platform_hal_get_status(&hal_status)) {
            // Hold priority checked first
            if (hal_status.touch_held) {
                state_machine_on_touch_hold(&g_device_ctx);
            } else if (hal_status.touch_pressed) {
                state_machine_on_touch_tap(&g_device_ctx);
            }
        }

        // Handle USB connection/disconnection
        bool usb_connected_curr = usb_session_is_connected();
        static bool usb_connected_prev = false;

        if (usb_connected_curr && !usb_connected_prev) {
            // USB just connected
            state_machine_on_usb_connect(&g_device_ctx);
            usb_session_start_auth_challenge(); // Start authentication challenge
        } else if (!usb_connected_curr && usb_connected_prev) {
            // USB just disconnected
            state_machine_on_usb_disconnect(&g_device_ctx); // Call a specific disconnect handler
            usb_session_end(); // End the USB session
        }
        usb_connected_prev = usb_connected_curr;

        // Check for pending actions and update UI feedback
        ui_status_t ui_status;
        ui_feedback_from_state(&g_device_ctx, NULL, &ui_status);

        // Implement autofill logic here based on state and UI feedback
        // This logic should ONLY execute if the state machine explicitly allows typing.
        if (g_device_ctx.state == DEVICE_CONFIRM_TYPE) {
            credential_record_t pending_credential;
            char pending_origin[MAX_ORIGIN_LEN];
            if (state_machine_get_pending_action(&g_device_ctx, &pending_credential, pending_origin, sizeof(pending_origin))) {
                // If the state implies typing is confirmed, proceed.
                // This typically means the user has acknowledged with touch/hold.
                if (usb_session_type_credentials(&pending_credential, pending_origin)) {
                    // Typing successful, transition device state (e.g., back to unlocked/idle)
                    state_machine_post_credential_action(&g_device_ctx); // Assuming this function exists.
                } else {
                    // Handle typing failure.
                    state_machine_reset_pending_action(&g_device_ctx); // Assuming this function exists.
                }
            }
        }

        // Update LED state based on the current LED pattern from ui_status
        g_device_ctx.current_led_pattern = ui_status.led_pattern;
        update_led_state(&g_device_ctx, HAL_GetTick()); // Use HAL_GetTick for current time


        // Add a small delay or yield if necessary to prevent busy-waiting
        platform_hal_delay_ms(1);
    }
    // Should never reach here
    return 0;
}

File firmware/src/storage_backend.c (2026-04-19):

#include <string.h>
#include <stdbool.h>
#include <stdint.h>

#include "stm32u5xx_hal.h" // Include HAL header for FLASH operations

#include "storage_backend.h"

// IMPORTANT: Define flash sector addresses and sizes based on your specific STM32U5xx MCU and linker script.
// These are EXAMPLE values and MUST be adjusted for your target hardware.
// Consult the STM32U5xx reference manual and your project's linker script (.ld file) for correct values.
// For example, if using the first two 16KB sectors of a device with 16KB sectors:
#define FLASH_SECTOR_A_ADDR 0x08000000 // Start address of Flash Sector A (e.g., Sector 0)
#define FLASH_SECTOR_B_ADDR 0x08004000 // Start address of Flash Sector B (e.g., Sector 1, assuming 16KB sectors)
#define FLASH_SECTOR_SIZE   0x4000     // Size of one flash sector (e.g., 16KB = 0x4000 bytes)
#define FLASH_BANK_SIZE     0x200000   // Total Flash memory size of the device (e.g., 2MB = 0x200000 bytes)

// Ensure that the total payload size does not exceed the sector size minus metadata.
#if STORAGE_BACKEND_MAX_PAYLOAD > (FLASH_SECTOR_SIZE - sizeof(storage_slot_header_t))
#error "STORAGE_BACKEND_MAX_PAYLOAD is too large for the configured flash sector size."
#endif

typedef struct {
  uint32_t generation;
  uint32_t schema_version;
  uint32_t payload_len;
  uint8_t crc8[1]; // Simple CRC for header validation
} storage_slot_header_t;

typedef struct {
  storage_slot_header_t header;
  uint8_t payload[STORAGE_BACKEND_MAX_PAYLOAD];
} storage_slot_internal_t;

static bool g_storage_initialized = false;

static uint8_t calculate_crc8(const uint8_t *data, size_t len) {
    uint8_t crc = 0u;
    for (size_t i = 0; i < len; ++i) {
        crc ^= data[i];
    }
    return crc;
}

static bool read_flash_sector(uint32_t address, uint8_t *buffer, size_t size) {
    // Basic address validation. Ensure the address is within the flash memory range.
    if (address < FLASH_BASE || address >= (FLASH_BASE + FLASH_BANK_SIZE)) {
        return false;
    }
    // Ensure the read size does not exceed the sector size or go beyond the flash boundaries.
    if (size > FLASH_SECTOR_SIZE || (address + size) > (FLASH_BASE + FLASH_BANK_SIZE)) {
        return false;
    }
    // Read directly from the memory-mapped flash address.
    // This is the standard way to read from memory-mapped flash.
    memcpy(buffer, (uint8_t *)address, size);
    return true;
}

static bool write_flash_sector(uint32_t address, const uint8_t *data, size_t size) {
    HAL_StatusTypeDef status;
    uint32_t sector_error; // Unused variable, but kept for HAL function signature compatibility if needed.

    // Basic address validation. Ensure the address is within the flash memory range.
    if (address < FLASH_BASE || address >= (FLASH_BASE + FLASH_BANK_SIZE)) {
        return false;
    }
    // Ensure the write size does not exceed the sector size or go beyond the flash boundaries.
    if (size > FLASH_SECTOR_SIZE || (address + size) > (FLASH_BASE + FLASH_BANK_SIZE)) {
        return false;
    }

    // Unlock flash
    status = HAL_FLASH_Unlock();
    if (status != HAL_OK) {
        return false;
    }

    // Erase the sector before writing
    FLASH_EraseInitTypeDef erase_init;
    erase_init.TypeErase = FLASH_TYPEERASE_SECTORS; // Use sector erase

    // Determine the sector number from the address. This mapping is device-specific.
    // You need to consult the STM32U5xx reference manual for the correct sector mapping.
    // Example mapping for STM32U573: Sectors 0-3 are 16KB, Sectors 4-7 are 128KB.
    // The following logic assumes a simple mapping where FLASH_SECTOR_A_ADDR and FLASH_SECTOR_B_ADDR
    // correspond to specific, contiguous sectors. Adjust this logic based on your MCU's memory map.
    uint32_t sector_number;
    uint32_t bank_number = FLASH_BANK_1; // Default to Bank 1, adjust if using dual-bank features

    // This mapping logic is CRITICAL and must match your linker script and MCU's flash layout.
    // Example: If FLASH_SECTOR_A_ADDR is the start of Sector 0, and FLASH_SECTOR_B_ADDR is the start of Sector 1.
    if (address == FLASH_SECTOR_A_ADDR) {
        sector_number = FLASH_SECTOR_0; // Assuming Sector A maps to Sector 0
    } else if (address == FLASH_SECTOR_B_ADDR) {
        sector_number = FLASH_SECTOR_1; // Assuming Sector B maps to Sector 1
    } else {
        // If the address doesn't match known sectors, it's an error.
        HAL_FLASH_Lock(); // Lock flash before returning
        return false; // Unknown sector address
    }
    erase_init.Sector = sector_number;
    erase_init.NbSectors = 1; // Erase only one sector

    // Ensure the correct bank is selected if applicable (for dual-bank devices)
    // This requires knowing which bank FLASH_SECTOR_A_ADDR and FLASH_SECTOR_B_ADDR belong to.
    // For simplicity, assuming single bank or both sectors are in Bank 1.
    // erase_init.Banks = bank_number; // Uncomment and set correctly if using dual banks

    status = HAL_FLASHEx_Erase(&erase_init, &sector_error);
    if (status != HAL_OK) {
        HAL_FLASH_Lock(); // Lock flash before returning
        return false;
    }

    // Program the data in 32-bit words for efficiency
    // The HAL_FLASH_Program function programs in 32-bit words.
    for (size_t i = 0; i < size; i += 4) {
        uint32_t data_word = 0;
        // Copy up to 4 bytes for the current word, handling the end of the data
        size_t bytes_to_copy = (size - i < 4) ? (size - i) : 4;
        memcpy(&data_word, data + i, bytes_to_copy);

        // Ensure we don't write past the end of the sector if size is smaller than sector size
        // This check is important to avoid writing beyond the intended data size within the sector.
        if (address + i >= (address + size)) break; // Stop if we've written all requested data

        status = HAL_FLASH_Program(FLASH_TYPEPROGRAM_WORD, address + i, data_word);
        if (status != HAL_OK) {
            HAL_FLASH_Lock(); // Lock flash before returning
            return false;
        }
    }

    // Lock flash
    status = HAL_FLASH_Lock();
    if (status != HAL_OK) {
        return false;
    }

    return true;
}

static bool is_slot_valid(const storage_slot_internal_t *slot) {
    // Check for null pointer, zero payload length, or payload exceeding max capacity
    if (!slot || slot->header.payload_len == 0 || slot->header.payload_len > STORAGE_BACKEND_MAX_PAYLOAD) {
        return false;
    }
    // Recalculate CRC and compare
    // Ensure the CRC calculation covers the header fields *excluding* the CRC field itself.
    uint8_t calculated_crc = calculate_crc8((uint8_t *)&slot->header, sizeof(storage_slot_header_t) - sizeof(slot->header.crc8));
    return calculated_crc == slot->header.crc8[0];
}
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

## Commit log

2026-04-09 Harden firmware command path and complete extension interaction wiring (#1)
    * Add SVJ generator with RP2040 pin mapping
    * Generate RP2040 board SVJ and ERC report
    * Fix USB series resistors and complete RP2040 QSPI boot flash
    * Add custom firmware scaffold with security policy
    * Fix touch-gated fill test flow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
2026-04-11 feat: Add STM32U5 platform HAL header with pin macros and function prototypes
2026-04-11 feat(firmware): add STM32U5 HAL implementation for platform_hal.c
2026-04-12 feat: Configure STM32U5 cross-compilation build and presets
2026-04-12 feat: Implement STM32U5 HAL platform layer
2026-04-12 feat: Implement USB HID keyboard HAL driver
2026-04-12 fix: Apply production hardening and guard debug logs
    [platform_hal.c]
2026-04-12 fix: Remove unused shifted_ascii_to_hid_map from platform_hal.c
    [platform_hal.c]
2026-04-12 refactor: Replace root platform_hal.c with host-test stub
    [platform_hal.c]
2026-04-12 feat: implement composite USB device with HID keyboard, custom HID, and mass storage
2026-04-12 feat: create self-contained WebHID companion app for device management
2026-04-12 fix: address cryptographic, secure boot, and storage integrity issues
    [crypto_engine.c, storage_backend.c]
2026-04-12 refactor: add volatile qualifiers and fix concurrency issues for interrupt safety
    [main.c]
2026-04-12 fix: implement complete UX flow and device behavior audit with LED, touch, TOTP, PIN, and wipe fixes
2026-04-12 refactor: update state_machine_get_pending_action to handle credential retrieval and switch to platform_hal_delay_ms in main loop
2026-04-12 fix: enforce secure boot and zeroize secrets in state machine, session, and crypto modules
    [main.c]
2026-04-12 Production hardening: full security + stability + UX audit pass
    [crypto_engine.c, main.c, pcd_hal.c]
2026-04-12 fix: improve nonce handling and stub fallback security in crypto_engine_encrypt_password
    [crypto_engine.c]
2026-04-19 Revise README for STM32U5 Password Holder
    Updated project description to clarify features and purpose.
2026-04-19 fix: Refactor and correct password decryption and AEAD implementation
    [crypto_engine.c]
2026-04-19 fix(crypto): Refactor password encryption and align EC key operations for ATECC
    [crypto_engine.c]
2026-04-19 feat: Implement core ATECC608A driver functions and update SECURITY_TODO
2026-04-19 feat: Integrate ATECC driver and refine `crypto_engine` production checks
2026-04-19 fix: Correct ATECC driver and crypto engine binding/hashing logic
    [crypto_engine.c]
2026-04-19 fix: Remove `crypto_engine_hash256` duplicate and update `main.c` manifest verification
    [main.c]
2026-04-19 fix: Replace placeholders in ATECC driver and secure boot
    [main.c]
2026-04-19 docs: Implement ATECC608A driver stubs
2026-04-19 feat: Add ATECC608A driver interface definitions
2026-04-19 feat: Add stm32u5xx_hal.h header file
2026-04-19 fix: Remove development fallbacks and simulation logic from ATECC driver
    [crypto_engine.c]
2026-04-19 fix: Remove dummy secure boot data and USB session seed
    [main.c]
2026-04-19 fix: Implement dual-flash atomic storage using HAL_FLASH
    [storage_backend.c]
2026-04-19 fix: Implement USB MSC and platform HAL functions
    [platform_hal.c]
2026-04-19 fix: Remove simulation comments from ATECC driver and crypto engine
    [crypto_engine.c]
2026-04-19 fix: Remove redundant production check in password fingerprint
    [crypto_engine.c]
2026-04-19 fix: Implement atomic flash write and read operations
    [storage_backend.c]
2026-04-19 docs: Update ATECC608A driver header with detailed comments
2026-04-19 fix: Remove dummy secure boot data placeholders
    [main.c]
2026-04-19 fix: Implement real HAL linkage in platform_hal.c
    [platform_hal.c]
